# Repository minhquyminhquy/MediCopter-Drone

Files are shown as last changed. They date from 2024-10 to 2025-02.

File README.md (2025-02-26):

# MediCopter: DIY Automated Drone for Medical Supply Delivery!

Welcome to our space! We are Quy, Vinh, and Khoa from Gia Dinh High School, Vietnam. Our project is MediCopter, an automated drone to deliver medical supply to rurals areas. In this github documentation, you can find our journey to build it from stratch, codes, and media. You can also listen to our presentation at the end of this document.

<div align="center">
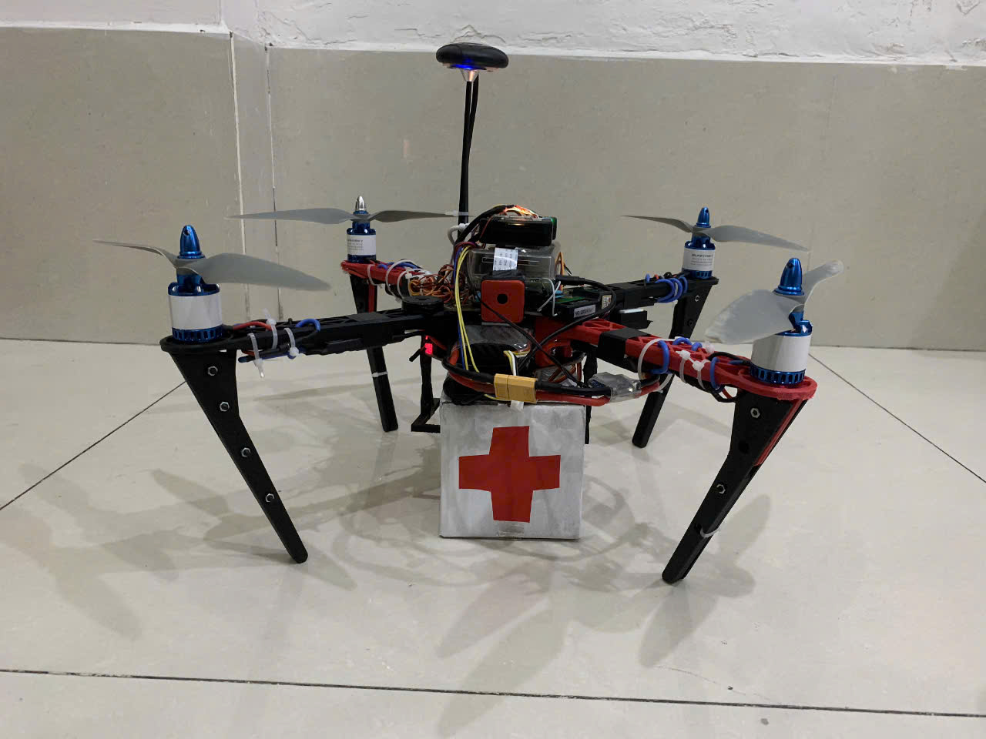
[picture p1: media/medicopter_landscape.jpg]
Poster - MediCopter

</div>

# Introduction
Our drone primarily consist of multicopter frame, various sensors, and a power manangement system. In order to run automatically, there is an **Raspberry Pi 4** that run Python script to maneuver the drone to the desired duration, meanwhile sending GPS location back to the computer and detecting obstacles. To ensure smooth flight, there is a **Pixhawk 2.4.8** fly controller that control the balance of the flight using PID, which we had tune for better balance.
## Motivation:
In the Mekong Delta, which is an rural area located in the southern Vietnam, there is **44%** of hospitals that are not equipped with sufficient medical supplies, leading to the emergence of on-demand medicals. In the emergency need of a certain medical supply, the traditional vehicles, like ambulance, are not capable of reaching these hospitals on-time, leading to bad situations.

That is why we developed MediCopter, a solution that can significantly speed up the transportation times of medical supplies by using drones, one of the most modern means of transportation. With the capabilities of holding up to 2kg, and peak speed of 100 km/h, MediCopter can deliver most of the supplies needed for an emergency.
## Key features

* Capable of holding maximum of 2kg by the 3D printed arm and servor
* Automatically fly to the destination by using GPS and automatically update on the server
* Using Object Detection to detect obstacles like bird, kites, building during maneuver

Poster - MediCopter

# Materials

## Hardware component

| Part | Components | Description |
|---|---|---|
| **Multicopter Frame**  | Frame with Power Distribution Board | Main structure for the drone |
| | 4 x 11x4.5 Propellers | Provides lift |
| | 4 Arms | Supports propellers |
| | 5000mAh LiPo Battery | Power source |
| | 4 x 40A Electronic Speed Controllers (ESC) | Controls motor speed |
| | 980 kV Brushless Motor | Drives propellers |
| **Flight Controller**  | Raspberry Pi 4 | Onboard processing |
| | Pixhawk 2.4.8 | Flight control system |
| | GPS | Navigation |
| **Add-ons** | Raspberry Pi Camera | Captures images and video |
| | Microphone & Speaker | Audio input and output |
| | SIM Module | Cellular connectivity |
| | USB Camera (for detecting landing area) | Assists in landing detection |

## Software Apps and Online Services

| Software/Service | Purpose |
|---|---|
| **ArduPilot** | Provides tools for PID tuning and calibration of the drone's flight controller. Allows fine-tuning of performance and stability. |
| **Python Libraries** | Essential libraries used for development: |
| | - **DroneKit**: Enables communication with the drone and control of flight operations.  |
| | - **OpenCV**: Used for image processing and computer vision tasks, such as object detection and tracking. |
| **Firebase** | Facilitates real-time location monitoring and data storage for the drone, allowing remote access to telemetry data. |
| **TensorFlow Lite** | Enables deployment of the MobileNet-SSD object detection model on the Raspberry Pi, allowing real-time object detection capabilities. |
| **SolidWorks** | Provides tools for 3D modeling and rendering of drone components, enabling visualization and design optimization. |

## Hand Tools and Fabrication Tools

| Tool | Purpose |
|---|---|
| **3D Printer** | Used for creating custom parts and components for the drone, allowing for rapid prototyping and design iterations. Supports various materials to enhance structural integrity. |
| **Electric Soldering Iron** | Essential for soldering electronic components onto the drone's circuit boards, ensuring reliable connections for optimal performance. Ideal for custom wiring and repairs. |

# Workflow
The workflow consists of 3 objects: Computer, Raspberry Pi, Pixhawk (Flight Controller)
## Pre-flight
1. **Connection**: The Raspberry Pi connects to the ThinkPad via Dynamic DNS and SSH. 
2. **Command Execution**: Commands are sent from the computer to execute Python scripts on the Raspberry Pi. 
3. **Preflight Setup**: Sensor calibration and battery checks are performed. 
## Mid-air
4. **Takeoff**: The Raspberry Pi commands the flight controller to spin the propellers. 
5. **Flight**: The flight controller adjusts motor speeds based on sensor data for stability. 
6. **Navigation**: The drone uses GPS for positioning and follows waypoints or manual inputs. 
7. **Video Streaming**: Video streaming is initiated. 
8. **Obstacle detection**: Detect obstacles (bird, building, etc)
## Landing
9. **Landing**: The flight controller commands the drone to gradually descend and land.
    
This workflow is mainly commanded by Raspberry Pi - Pixhawk Combination.
<div align="center">
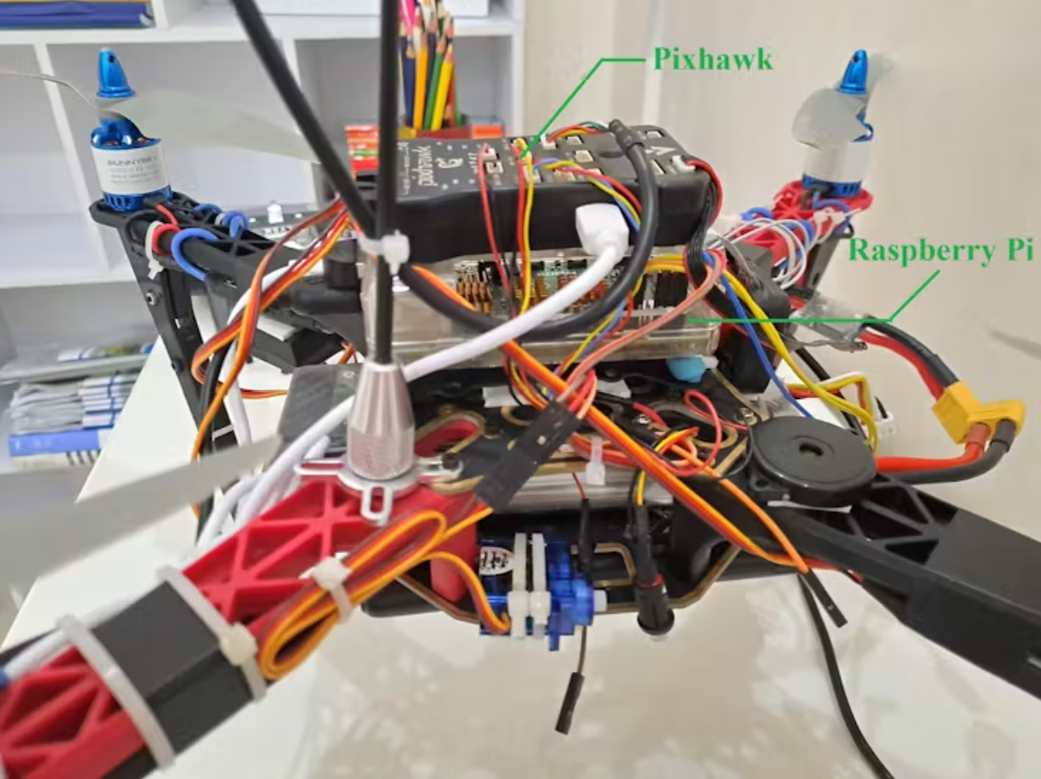
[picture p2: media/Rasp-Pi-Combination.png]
Raspberry Pi - Pixhawk Combination

</div>
Example code:
<div align="center">
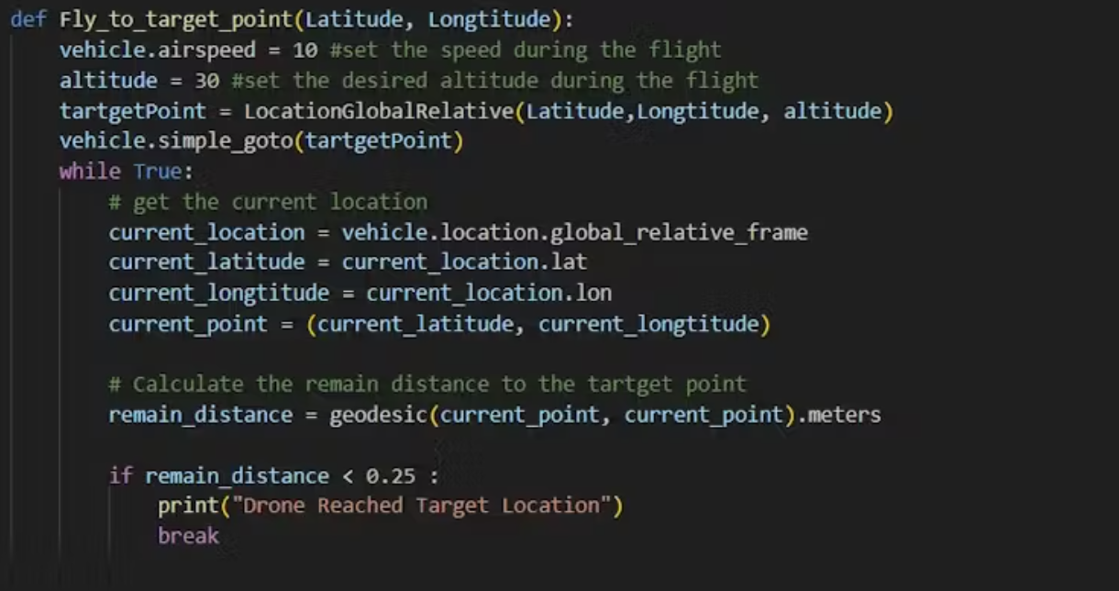
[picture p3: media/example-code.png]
Example code

</div>

# Building Process
Our journey have 2 phase: manual control (only Pixhawk) and autonomous control (Pixhawk and Raspberry Pi). You can find our assemling process in this youtube playlist.

MediCopter Assembling Playlist (https://youtube.com/playlist?list=PL21Xkm88JcA4obuWS0P6m1VQUeOZoDrcb&si=dXZTIC1rQ1kXRq51)

## Phase 1: Manual control with Pixhawk
### Building the frame
1. Connect Electronic Speed Controller (ESC) to Power Distribution Board (PDB)
<div align="center">
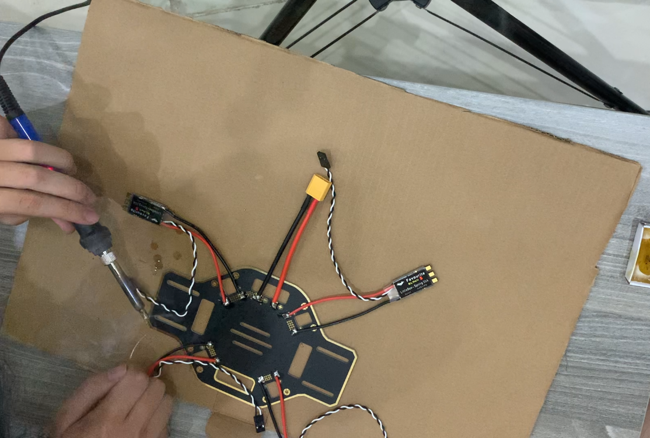
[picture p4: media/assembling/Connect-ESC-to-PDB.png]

</div>

2. Connect Brushless Motors to Arms
<div align="center">
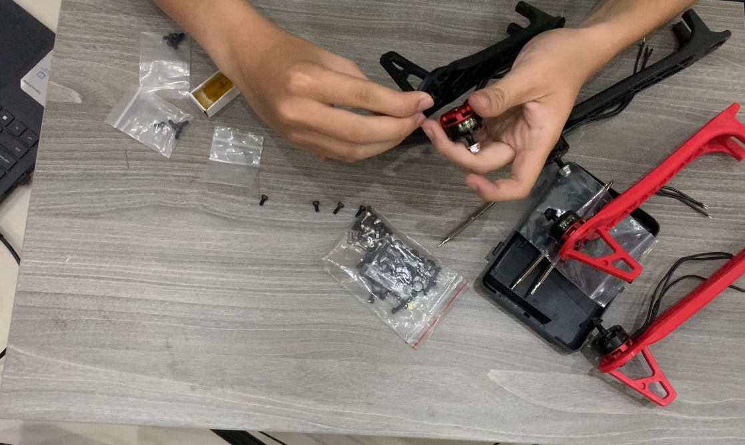
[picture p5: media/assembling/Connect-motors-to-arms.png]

</div>

3. Connect Arms to PDB
<div align="center">
Example cdeo
</div>

4. Connect Battery to PDB
<div align="center">
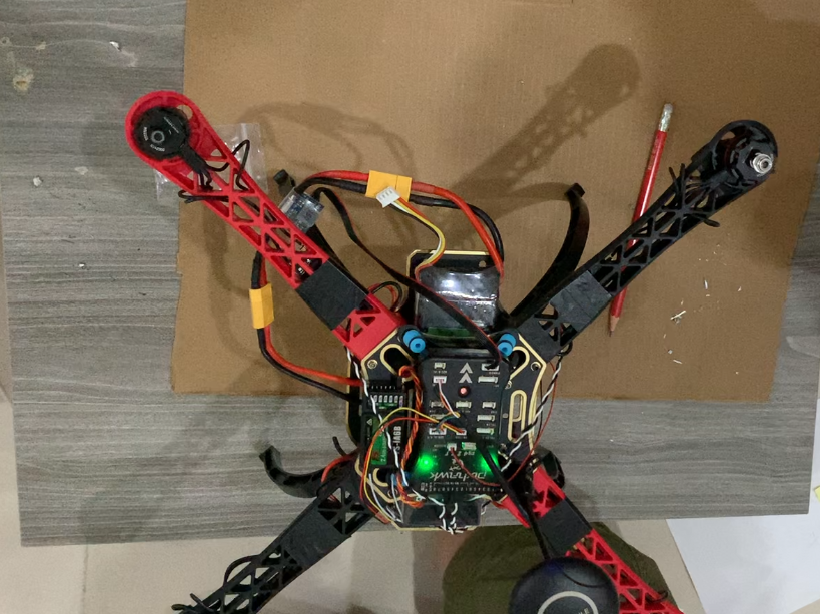
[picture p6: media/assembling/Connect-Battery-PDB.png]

</div>

5. Connect Pixhawk to PDB
<div align="center">
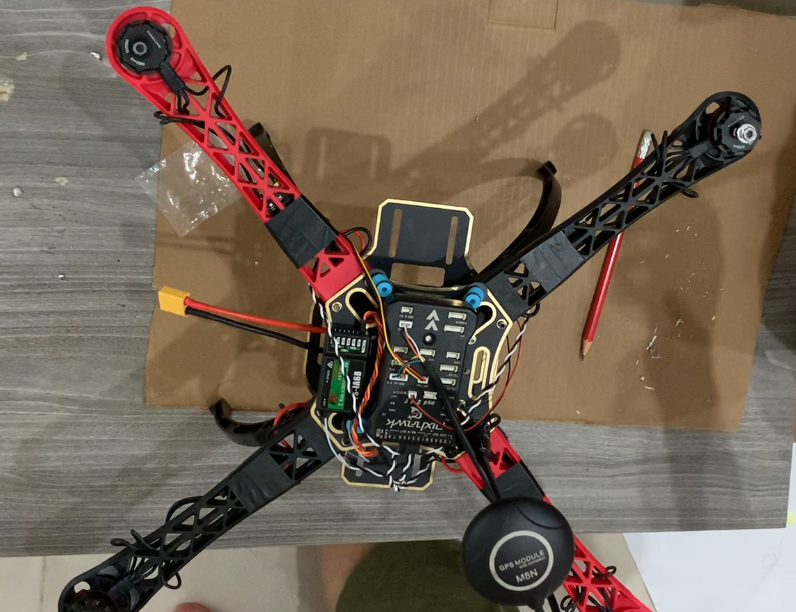
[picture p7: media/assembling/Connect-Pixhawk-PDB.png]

</div>

6. 3D printed the legs. The .stl file can be found in the folder 3D_components.

https://github.com/user-attachments/assets/169ed1b9-fe8f-40f5-9008-af87535a27e2

### Pixhawk Set-up
7. Calibration and PID Tuning with Ardupilot
<div align="center">
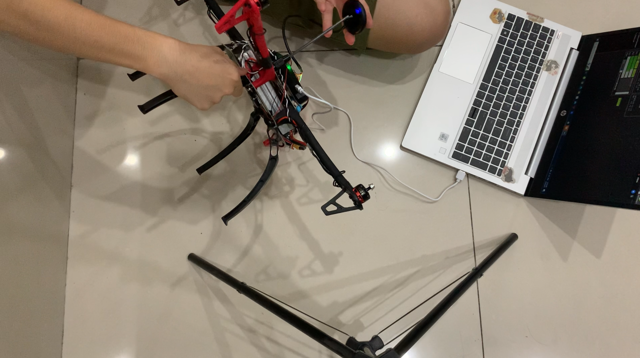
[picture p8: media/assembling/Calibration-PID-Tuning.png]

</div>
8. Spinning test #1. At this point, 2 ESCs burns, so we have to upgrade ESCs.
9. Connect new ESCs
<div align="center">
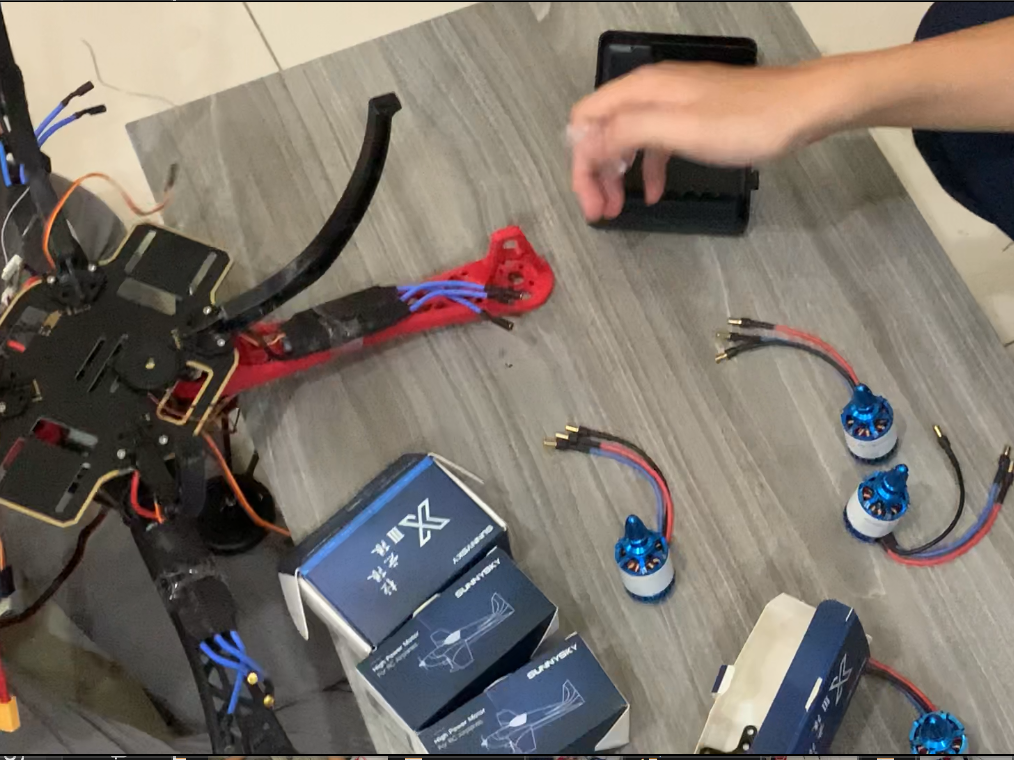
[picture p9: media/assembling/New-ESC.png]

</div>
8. Connect propellers

https://github.com/user-attachments/assets/d012decf-739c-4128-b322-1b5544648ba4

9. Spinning test #2. This time it spins perfectly
10. Field test #1 with controller.

https://github.com/user-attachments/assets/e171f9fb-7b1c-440d-8f37-c7a3fa3b547b

## Phase 2: Autonomous control
### Raspberry Pi Set-up
1. Connect Raspberry Pi

https://github.com/user-attachments/assets/7c1b4f54-8426-4d72-b6c0-2fdf0d123a5a

2. Connect Servo for Box Grabber. The 3D print file can be found at 3D_components/BoxGrabberPart1.stl and 3D_components/BoxGrabberPart2.stl
   
https://github.com/user-attachments/assets/4f15eef7-565c-4d65-8523-65f59fb4e886

3. Field test #2, automatic 

4. Designing Medical Box

https://github.com/user-attachments/assets/9040f761-5fff-42a1-a158-d3721a8c6d5b

### Develop MobileNet-SDD model
1. Get building, bird, kite images by web crawling
2. Train the model

https://github.com/user-attachments/assets/8a863976-2954-48e5-a756-10348f319502   

3. Deploy on Raspberry Pi

https://github.com/user-attachments/assets/92360678-1291-4f0b-8a1d-1a17bf62b5d6

### Camera Module
https://github.com/user-attachments/assets/2ed117ee-a2e5-4d44-a882-4a480ddee704
# Results & Achievements
On the demo of Aug 2023, our prototype are capable of flying automatically fly from point A to point B, and land safely. 

https://github.com/user-attachments/assets/ffb7f6d2-7564-45cc-9413-335dbed1bee8

This is a big win for us for the whole summer. Then, we validate our drone by bringing it into a science and engineering competition and won a Gold Medal. You can find the video of our presentation below by clicking into it:

<div align="center">

Presentation Video (https://www.youtube.com/watch?v=0ZWgyOTTF1M&t)

*AI-JAM Presentation Video*
</div>

We also got our hands on entrepreneurship by bringing this into a startup competition for high schoolers and university student. During the process, I learn the fundamentals of building a startup by crafting our business model canvas (checkout the ```final_round_pitching``` folder) and improve my public speaking skills by pitching it multiple times through different elimination round. Finally, we won a consolidation prize (around 200$) out of hundreds of teams. Such an amazing journey.

<div align="center">
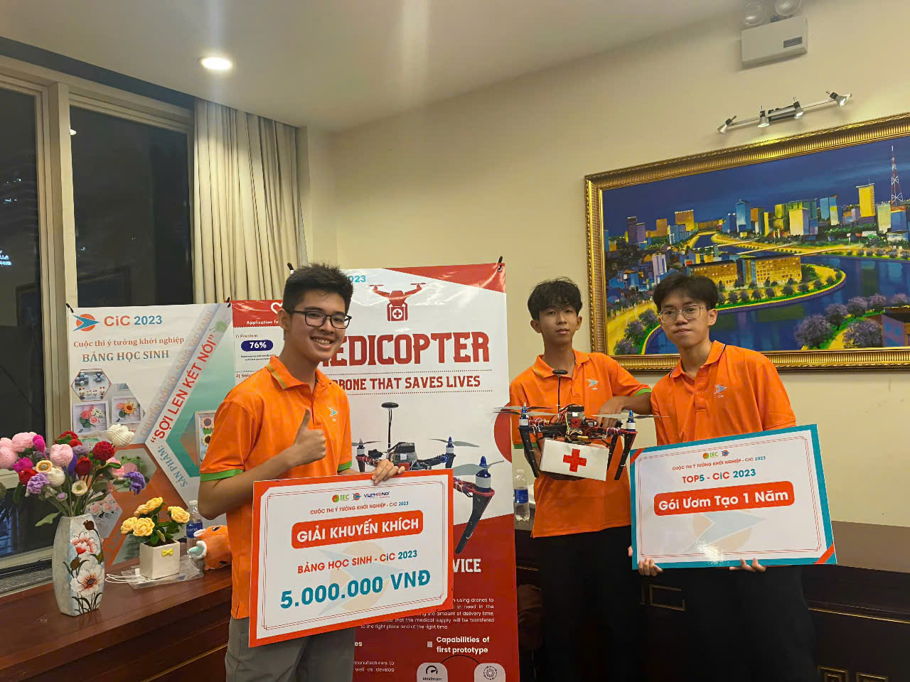
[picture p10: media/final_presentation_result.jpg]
Final Round

</div>

# Further development

Although we have succesfully develop other add-on like object detection, our drone are not capable of dodging the obstacle in real-time. This is one of the main development that we can improve in the future. For further distance and more payload, we can upgrade our battery and motors.

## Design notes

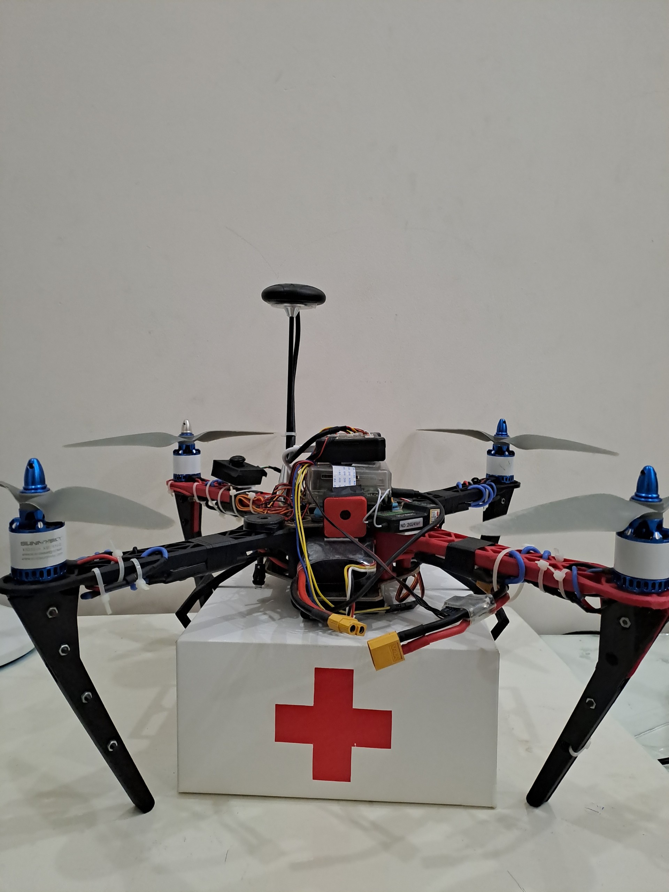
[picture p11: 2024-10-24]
final_round_pitching/Prototype_Img.png

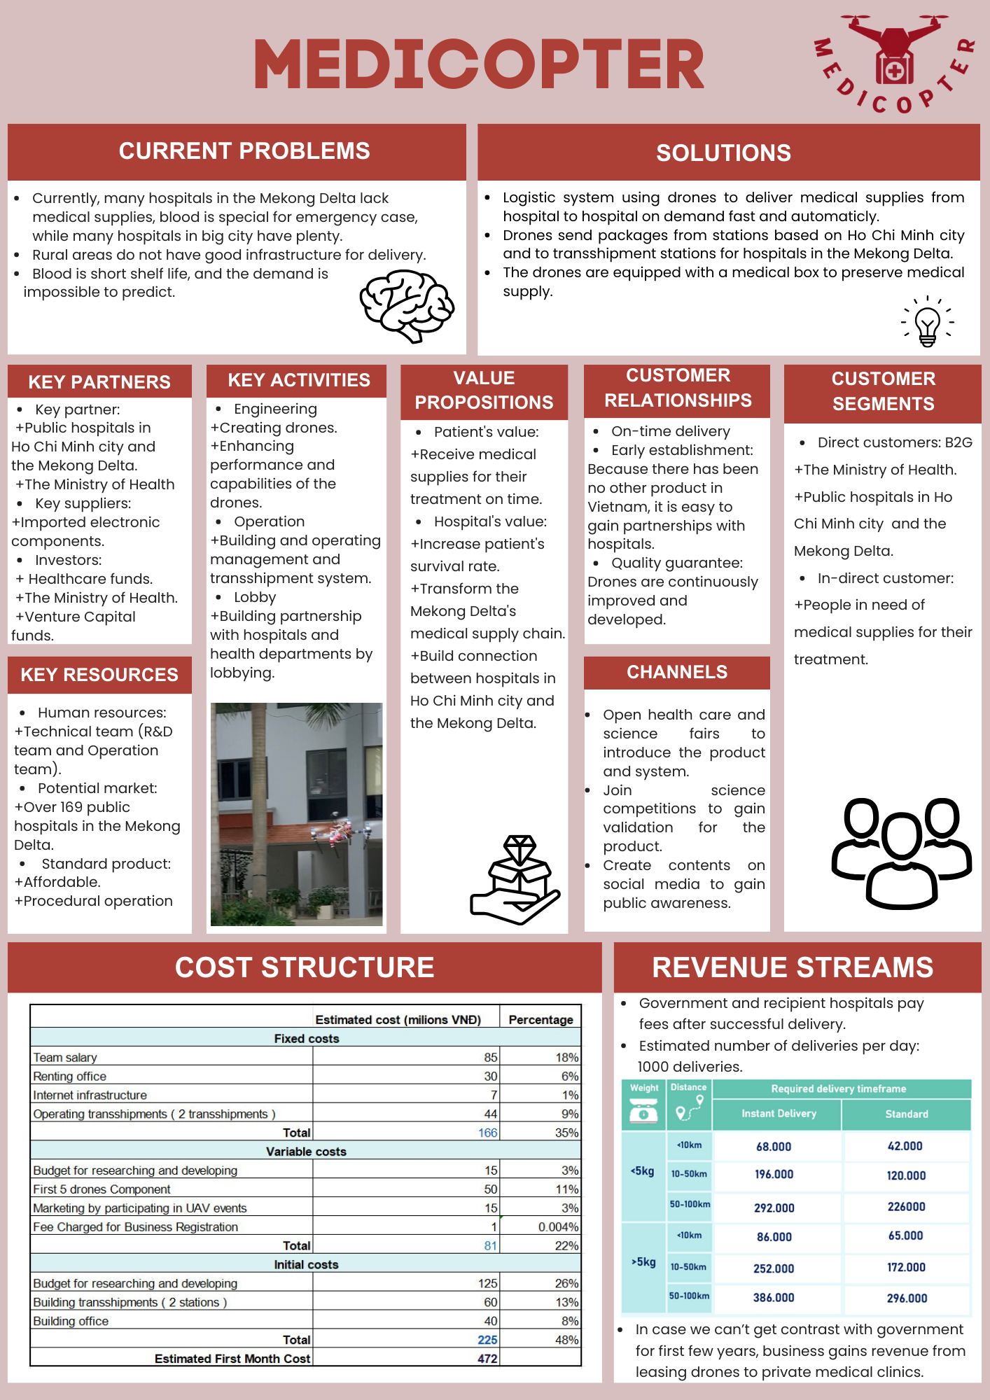
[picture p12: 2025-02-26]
final_round_pitching/Business_Model_Canvas.png

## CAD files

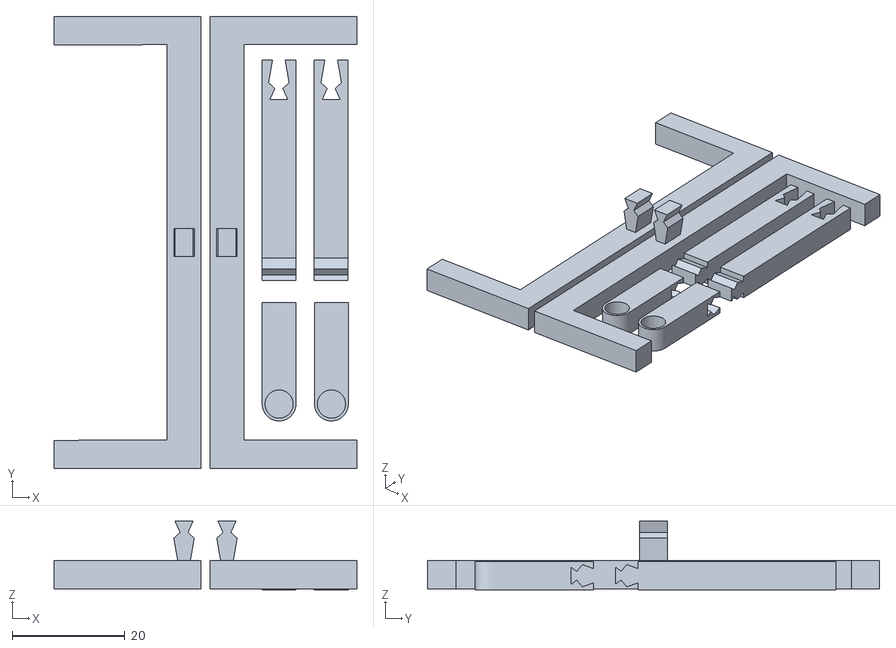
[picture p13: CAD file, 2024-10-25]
3D_components/BoxGrabberPart1.stl
53.6 x 80.0 x 12.2

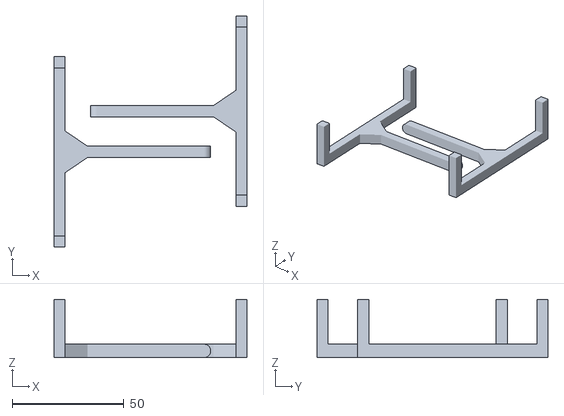
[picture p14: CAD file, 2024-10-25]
3D_components/BoxGrabberPart2.stl
86.2 x 103.2 x 26.0

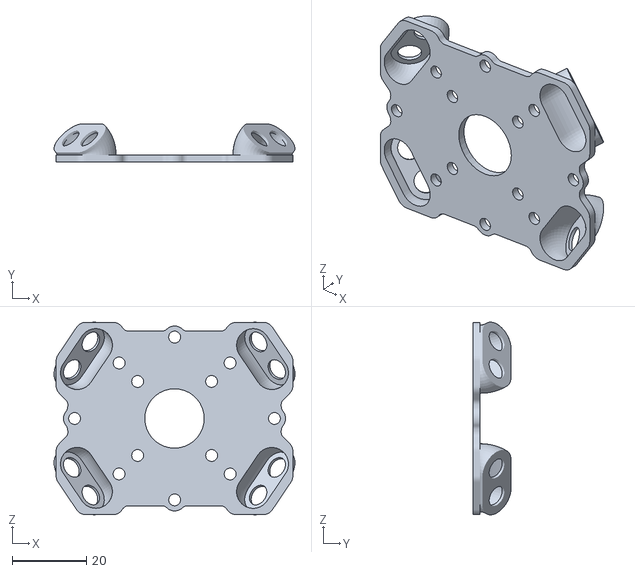
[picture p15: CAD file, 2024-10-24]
3D_components/VibrationDampeningPlate - Bot.STL
65.1 x 10.4 x 52.1

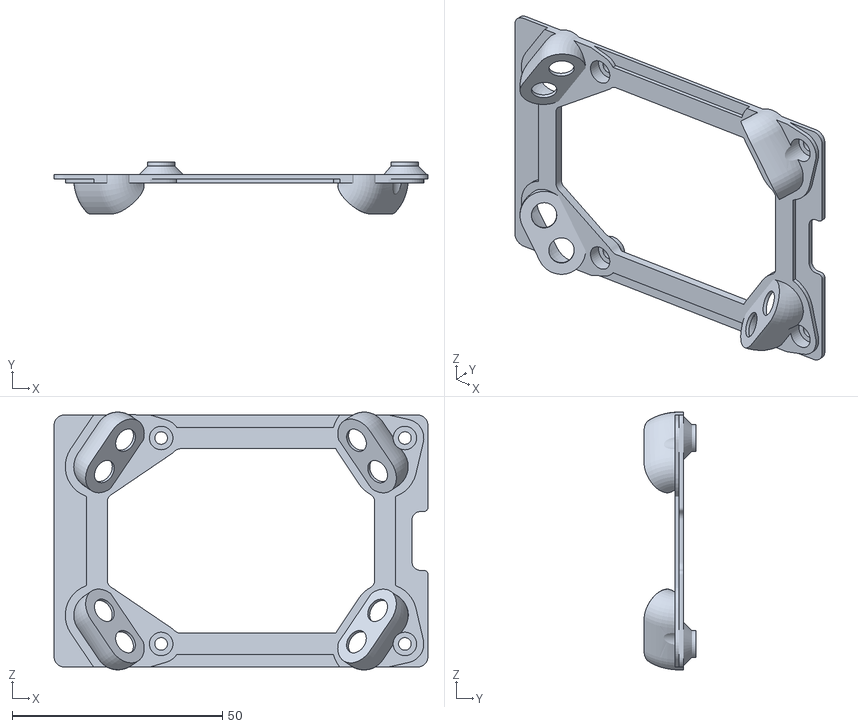
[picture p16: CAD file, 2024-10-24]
3D_components/VibrationDampeningPlate - Top.STL
89.0 x 12.4 x 61.4

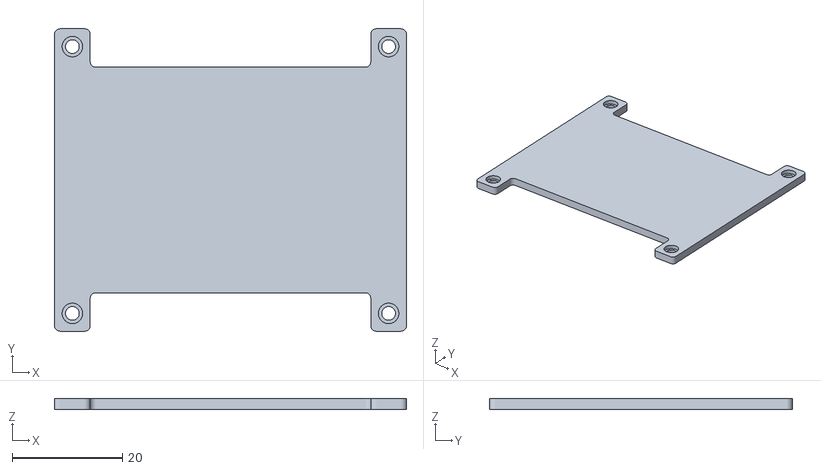
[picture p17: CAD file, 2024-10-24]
3D_components/RpiPixhawkMount.stl
64.0 x 55.0 x 2.00

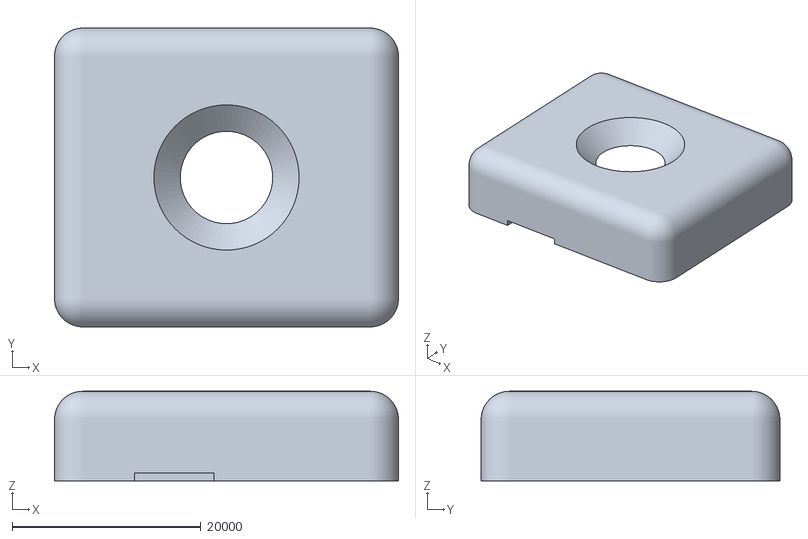
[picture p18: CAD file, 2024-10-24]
3D_components/CameraModuleCaseTop.stl
36500.0 x 31700.0 x 9500.0

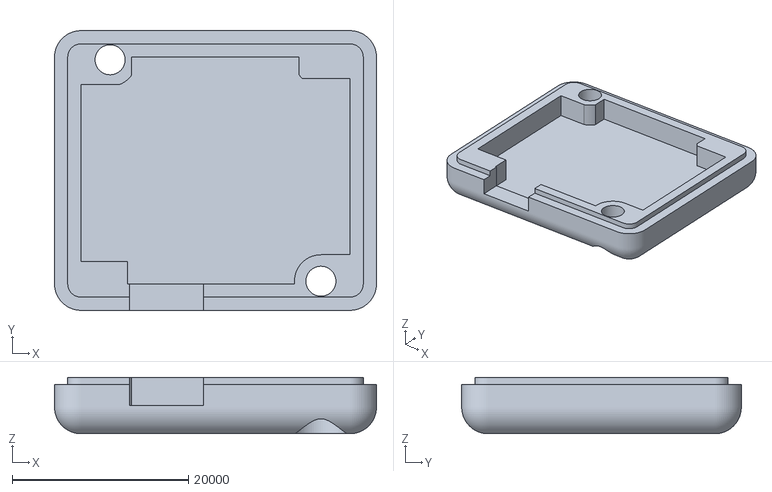
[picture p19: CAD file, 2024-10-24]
3D_components/CameraModuleCaseBottom.stl
36500.0 x 31700.0 x 6400.0

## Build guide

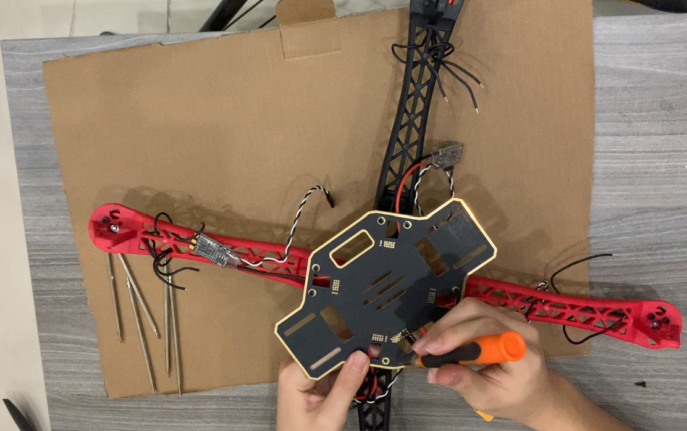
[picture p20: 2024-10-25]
media/assembling/Connect-Arm-to-PDB.png

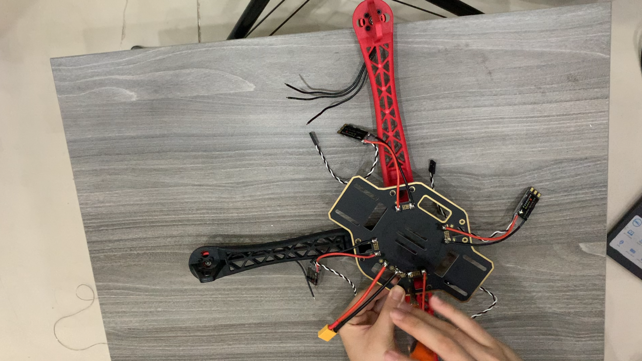
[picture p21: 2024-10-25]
media/assembling/Connect-arms-to-Power-Distribution-Board.png

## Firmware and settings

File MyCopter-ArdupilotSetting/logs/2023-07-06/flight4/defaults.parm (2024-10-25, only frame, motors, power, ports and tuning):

ATC_ANGLE_BOOST  1
ATC_ANG_LIM_TC   1.000000
ATC_ANG_PIT_P    4.500000
ATC_ANG_RLL_P    4.500000
ATC_ANG_YAW_P    4.500000
ATC_RATE_FF_ENAB 1
ATC_RATE_P_MAX   0.000000
ATC_RATE_R_MAX   0.000000
ATC_RATE_Y_MAX   0.000000
ATC_RAT_PIT_D    0.003600
ATC_RAT_PIT_FF   0.000000
ATC_RAT_PIT_FLTD 20.000000
ATC_RAT_PIT_FLTE 0.000000
ATC_RAT_PIT_FLTT 20.000000
ATC_RAT_PIT_I    0.135000
ATC_RAT_PIT_IMAX 0.500000
ATC_RAT_PIT_P    0.135000
ATC_RAT_PIT_SMAX 0.000000
ATC_RAT_RLL_D    0.003600
ATC_RAT_RLL_FF   0.000000
ATC_RAT_RLL_FLTD 20.000000
ATC_RAT_RLL_FLTE 0.000000
ATC_RAT_RLL_FLTT 20.000000
ATC_RAT_RLL_I    0.135000
ATC_RAT_RLL_IMAX 0.500000
ATC_RAT_RLL_P    0.135000
ATC_RAT_RLL_SMAX 0.000000
ATC_RAT_YAW_D    0.000000
ATC_RAT_YAW_FF   0.000000
ATC_RAT_YAW_FLTD 0.000000
ATC_RAT_YAW_FLTE 2.500000
ATC_RAT_YAW_FLTT 20.000000
ATC_RAT_YAW_I    0.018000
ATC_RAT_YAW_IMAX 0.500000
ATC_RAT_YAW_P    0.180000
ATC_RAT_YAW_SMAX 0.000000
BATT2_MONITOR    0
BATT3_MONITOR    0
BATT4_MONITOR    0
BATT5_MONITOR    0
BATT6_MONITOR    0
BATT7_MONITOR    0
BATT8_MONITOR    0
BATT9_MONITOR    0
BATT_MONITOR     0
FLTMODE1         0
FLTMODE2         0
FLTMODE3         0
FLTMODE4         0
FLTMODE5         0
FLTMODE6         0
FLTMODE_CH       5
FRAME_CLASS      0
FRAME_TYPE       1
INS_GYRO_FILTER  20
INS_HNTCH_ENABLE 0
MOT_BAT_CURR_MAX 0.000000
MOT_BAT_CURR_TC  5.000000
MOT_BAT_IDX      0
MOT_BAT_VOLT_MAX 0.000000
MOT_BAT_VOLT_MIN 0.000000
MOT_BOOST_SCALE  0.000000
MOT_HOVER_LEARN  2
MOT_PWM_MAX      2000
MOT_PWM_MIN      1000
MOT_PWM_TYPE     0
MOT_SAFE_DISARM  0
MOT_SAFE_TIME    1.000000
MOT_SLEW_DN_TIME 0.000000
MOT_SLEW_UP_TIME 0.000000
MOT_SPIN_ARM     0.100000
MOT_SPIN_MAX     0.950000
MOT_SPIN_MIN     0.150000
MOT_SPOOL_TIME   0.500000
MOT_THST_EXPO    0.650000
MOT_THST_HOVER   0.350000
MOT_YAW_HEADROOM 200
SERIAL0_BAUD     115
SERIAL0_PROTOCOL 2
SERIAL1_BAUD     57
SERIAL1_OPTIONS  0
SERIAL1_PROTOCOL 2
SERIAL2_BAUD     57
SERIAL2_OPTIONS  0
SERIAL2_PROTOCOL 2
SERIAL3_BAUD     38
SERIAL3_OPTIONS  0
SERIAL3_PROTOCOL 5
SERIAL4_BAUD     38
SERIAL4_OPTIONS  0
SERIAL4_PROTOCOL 5
SERIAL5_BAUD     57
SERIAL5_OPTIONS  0
SERIAL5_PROTOCOL -1
SERVO1_FUNCTION  33
SERVO1_MAX       1900
SERVO1_MIN       1100
SERVO1_REVERSED  0
SERVO1_TRIM      1500
SERVO2_FUNCTION  34
SERVO2_MAX       1900
SERVO2_MIN       1100
SERVO2_REVERSED  0
SERVO2_TRIM      1500
SERVO3_FUNCTION  35
SERVO3_MAX       1900
SERVO3_MIN       1100
SERVO3_REVERSED  0
SERVO3_TRIM      1500
SERVO4_FUNCTION  36
SERVO4_MAX       1900
SERVO4_MIN       1100
SERVO4_REVERSED  0
SERVO4_TRIM      1500
SERVO5_FUNCTION  0
SERVO5_MAX       1900
SERVO5_MIN       1100
SERVO5_REVERSED  0
SERVO5_TRIM      1500
SERVO6_FUNCTION  0
SERVO6_MAX       1900
SERVO6_MIN       1100
SERVO6_REVERSED  0
SERVO6_TRIM      1500
SERVO7_FUNCTION  0
SERVO7_MAX       1900
SERVO7_MIN       1100
SERVO7_REVERSED  0
SERVO7_TRIM      1500
SERVO8_FUNCTION  0
SERVO8_MAX       1900
SERVO8_MIN       1100
SERVO8_REVERSED  0
SERVO8_TRIM      1500
SERVO9_FUNCTION  0
SERVO9_MAX       1900
SERVO9_MIN       1100
SERVO9_REVERSED  0
SERVO9_TRIM      1500

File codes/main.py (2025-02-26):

"""
This script instructs the drone to take off, fly to target position, and land. 
Meanwhile recording the journey with the camera infront and update its location on Firebase.

Demo day: 20 Aug 2023
"""

import threading
import json
from dronekit import connect, VehicleMode, LocationGlobalRelative
import time
import cv2 
import pyrebase
import threading # Used for recording video simultaneously
from geopy.distance import geodesic 
import random  # Used for simulating obstacle detection

# Load configuration from JSON file
with open('config.json') as config_file:
    config = json.load(config_file)

# Constants from config
CONNECTING_STRING = config['connection']['connecting_string']
BAUD_RATE = config['connection']['baud_rate']

# Firebase Configuration and Initialization
FIREBASE_CONFIG = config['firebase']
firebase = pyrebase.initialize_app(FIREBASE_CONFIG)
db = firebase.database()

# Initialize Vehicle
vehicle = connect(CONNECTING_STRING, BAUD_RATE, wait_ready=True)  

# Initialize video capture and video writer
video_capture = cv2.VideoCapture(0)
fourcc = cv2.VideoWriter_fourcc(*'XVID')
output_file = cv2.VideoWriter('output2.avi', fourcc, 20.0, (640, 480))

def update_firebase_location():
    """Update the drone's current latitude and longitude to Firebase."""
    lat = vehicle.location.global_frame.lat 
    lon = vehicle.location.global_frame.lon
    data = {"LAT": lat, "LNG": lon}
    db.update(data)

def record_video():
    """Capture a frame from the camera and write it to the output file."""
    while True:
        ret, frame = video_capture.read()
        if ret:
            frame = cv2.flip(frame, 0)
            output_file.write(frame)
        time.sleep(0.1) 

def arm_and_takeoff(target_altitude):
    """Arm the drone and take off to the specified altitude."""
    while not vehicle.is_armable:
        print("Waiting for vehicle to initialise...")
        time.sleep(1)

    print("Arming motors...")
    vehicle.mode = VehicleMode("GUIDED")
    vehicle.armed = True

    while not vehicle.armed:
        print("Waiting for arming...")
        time.sleep(1)

    print("Taking off...")
    vehicle.simple_takeoff(target_altitude)  

    while True:
        print(f"Altitude: {vehicle.location.global_relative_frame.alt}")
        update_firebase_location()
        if vehicle.location.global_relative_frame.alt >= target_altitude * 0.95:
            print("Reached target altitude")
            break

def fly_to_target(latitude, longitude, target_alt, air_speed):         
    """Fly the drone to the specified latitude and longitude."""
    vehicle.airspeed = air_speed  
    target_point = LocationGlobalRelative(latitude, longitude, target_alt) 
    vehicle.simple_goto(target_point) 

    while True:
        # Get the current location
        current_location = vehicle.location.global_relative_frame
        current_latitude = current_location.lat
        current_longitude = current_location.lon
        current_point = (current_latitude, current_longitude)

        # Calculate the remaining distance to the target point
        remaining_distance = geodesic(current_point, target_point).meters

        update_firebase_location()  

        if remaining_distance < 0.25:
            print("Drone reached target location")
            break

        time.sleep(1)  

def land(): 
    """Land the drone safely."""
    vehicle.mode = VehicleMode("LAND")
    while True: 
        update_firebase_location() 
        altitude = vehicle.location.global_frame.alt
        if altitude < 0.2:
            print("Drone is on the ground")
            break 

def return_to_launch(): 
    """Return the drone to its launch point."""
    vehicle.mode = VehicleMode('RTL') 
    while True: 
        update_firebase_location() 
        altitude = vehicle.location.global_frame.alt
        if altitude < 0.2:
            print("Drone landed safely")
            break 

def print_drone_parameters():      
    """Print the current parameters of the drone."""
    print("DRONE STATUS:")
    print("1. Firmware Version:", vehicle.version)
    print("2. Global location:", vehicle.location.global_frame) 
    print("3. Battery:", vehicle.battery)  
    print("4. Mode:", vehicle.mode.name) 
    print("5. Armed Status:", vehicle.armed)

def monitor_battery():
    """Monitor the drone's battery status."""
    battery = vehicle.battery
    print("Battery Voltage: {}V".format(battery.voltage))
    print("Battery Level: {}%".format(battery.level))

    if battery.level < 20:
        print("Warning: Low battery! Returning to launch.")
        return_to_launch()

def check_for_obstacles():
    """Simulate obstacle detection. In a real scenario, replace this with actual sensor data."""
    obstacle_detected = random.choice([True, False])
    if obstacle_detected:
        print("Obstacle detected! Taking evasive action.")
        # Simple evasive maneuver: fly up and then return to original path
        vehicle.simple_takeoff(10)  # Ascend to 10 meters
        time.sleep(5)
        return_to_launch()

def create_waypoints():
    """Create a list of waypoints for the drone to fly to."""
    return [
        (10.80477, 106.71871),
        (10.80480, 106.71900),
        (10.80490, 106.71920),
        (10.80500, 106.71850)
    ]

def execute_mission(waypoints, target_alt, air_speed):
    """Execute the flight mission based on provided waypoints."""
    for waypoint in waypoints:
        latitude, longitude = waypoint
        fly_to_target(latitude, longitude, target_alt, air_speed)
        monitor_battery()
        check_for_obstacles()

def main():
    video_thread = threading.Thread(target=record_video)
    video_thread.daemon = True  
    video_thread.start()

    target_altitude = 6
    air_speed = 1
    print_drone_parameters() 
    arm_and_takeoff(target_altitude)

    waypoints = create_waypoints()
    execute_mission(waypoints, target_alt=target_altitude, 
                    air_speed=air_speed)

    land()
    
    video_capture.release()
    output_file.release()

if __name__ == "__main__":
    main()

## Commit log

2024-10-24 Add Introduction and materials
2024-10-24 Upload 3D print file, media, object detection model
    [BoxGrabber.stl, CameraModuleCaseBottom.stl, CameraModuleCaseTop.stl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]
2024-10-25 Upload Demo Codes on Jul 2023
    [defaults.parm, mav.parm]
2024-10-25 Change folder management
    [BoxGrabber.stl, CameraModuleCaseBottom.stl, CameraModuleCaseTop.stl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]
2024-10-25 Upload rotated image
    [BoxGrabber.stl, BoxGrabberPart1.stl, BoxGrabberPart2.stl]
2024-10-25 Add New ESC image
2025-02-26 fix typo in code folder
    [ArmedModeTest.py, DroneComputer2WayAudio.py, FlaskRealtimeCamera#2.py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]
2025-02-26 upload media and pitching materials
